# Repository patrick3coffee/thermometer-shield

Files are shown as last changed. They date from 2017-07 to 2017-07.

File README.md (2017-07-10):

# The Idea
I wanted a display of temperature and humidity and it exploded into this shield that functions as a thermostat, humidistat, and optostat (if that's even a word).
This project is my first attempt at creating a pcb. The design work is done in KiCAD. 

## Docs
See the PDF for the full shcematic and the SVGs for the inverted copper etching masks.

## Logical units of functionality
1. Display: this 4 digit, 7-segment display is driven by shift registers and transistors.
2. ULN2804 breakout: a transistor array for controlling 8 resistive or inductive loads.
    * Channels A through D plus G and H terminate to screw terminals. Channels G and H are connected in parallel to A and B respectively. This increases current capacity
    * Channels E through H terminat to pin headers.
    * To use G and H independently, four traces must be cut on the bottom of the board and the exposed inputs must connect to a desired arduino pin.
3. Button Array: Four buttons alter the output voltage in an array of voltage dividers
4. Photoresistor: Measures light.
5. RHT03: Measure temperatre and humidity.
6. I2C pin headers: allow for greater hackability.
7. All unused pins exposed.
    * D9 and D12
    * A2 and A3.
    * A4 and A5 in I2C header, but can be used for any purpose.

## The progression of scope creep  
There was more to this list that I think I forgot about, but these are the high points.
* Display temperature and humidity in garage. (done on a breadboard)  
* Do the same in the chicken coop.
* Make the hum/temp readings control things at specified thresholds.
* Make those thresholds settable on the front panel.
* Add a light sensor because the chicken coop needs the door shut at sunset and opened at sunrise.
* Expose all unused pins in useful ways for hackability.

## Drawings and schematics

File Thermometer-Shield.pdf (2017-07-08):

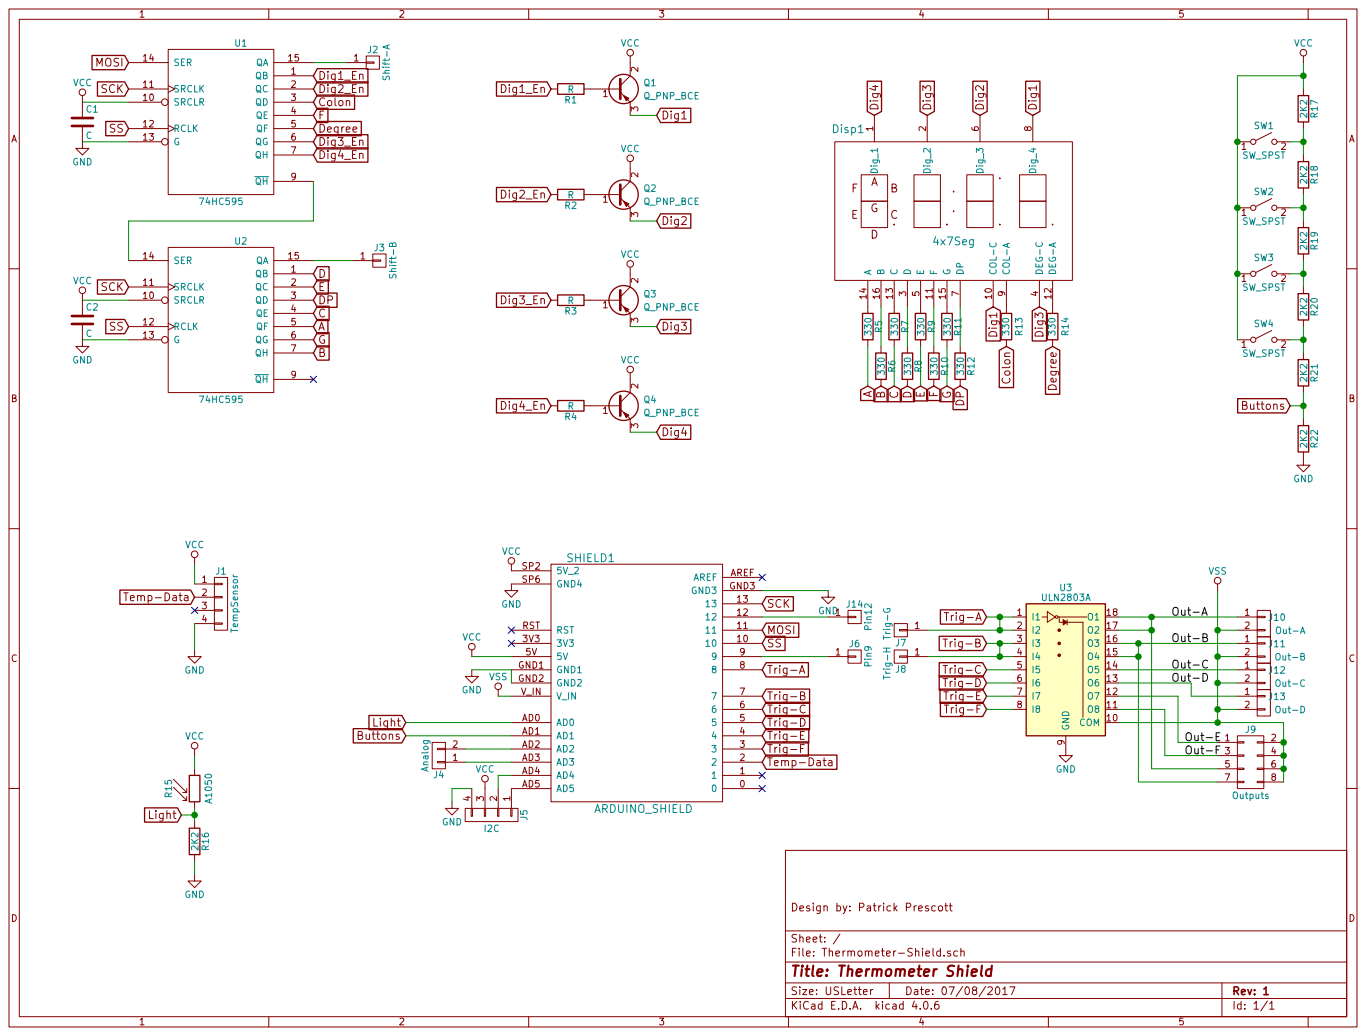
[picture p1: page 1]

Out-D | 2

Id: 1/1 Title: Thermometer Shield

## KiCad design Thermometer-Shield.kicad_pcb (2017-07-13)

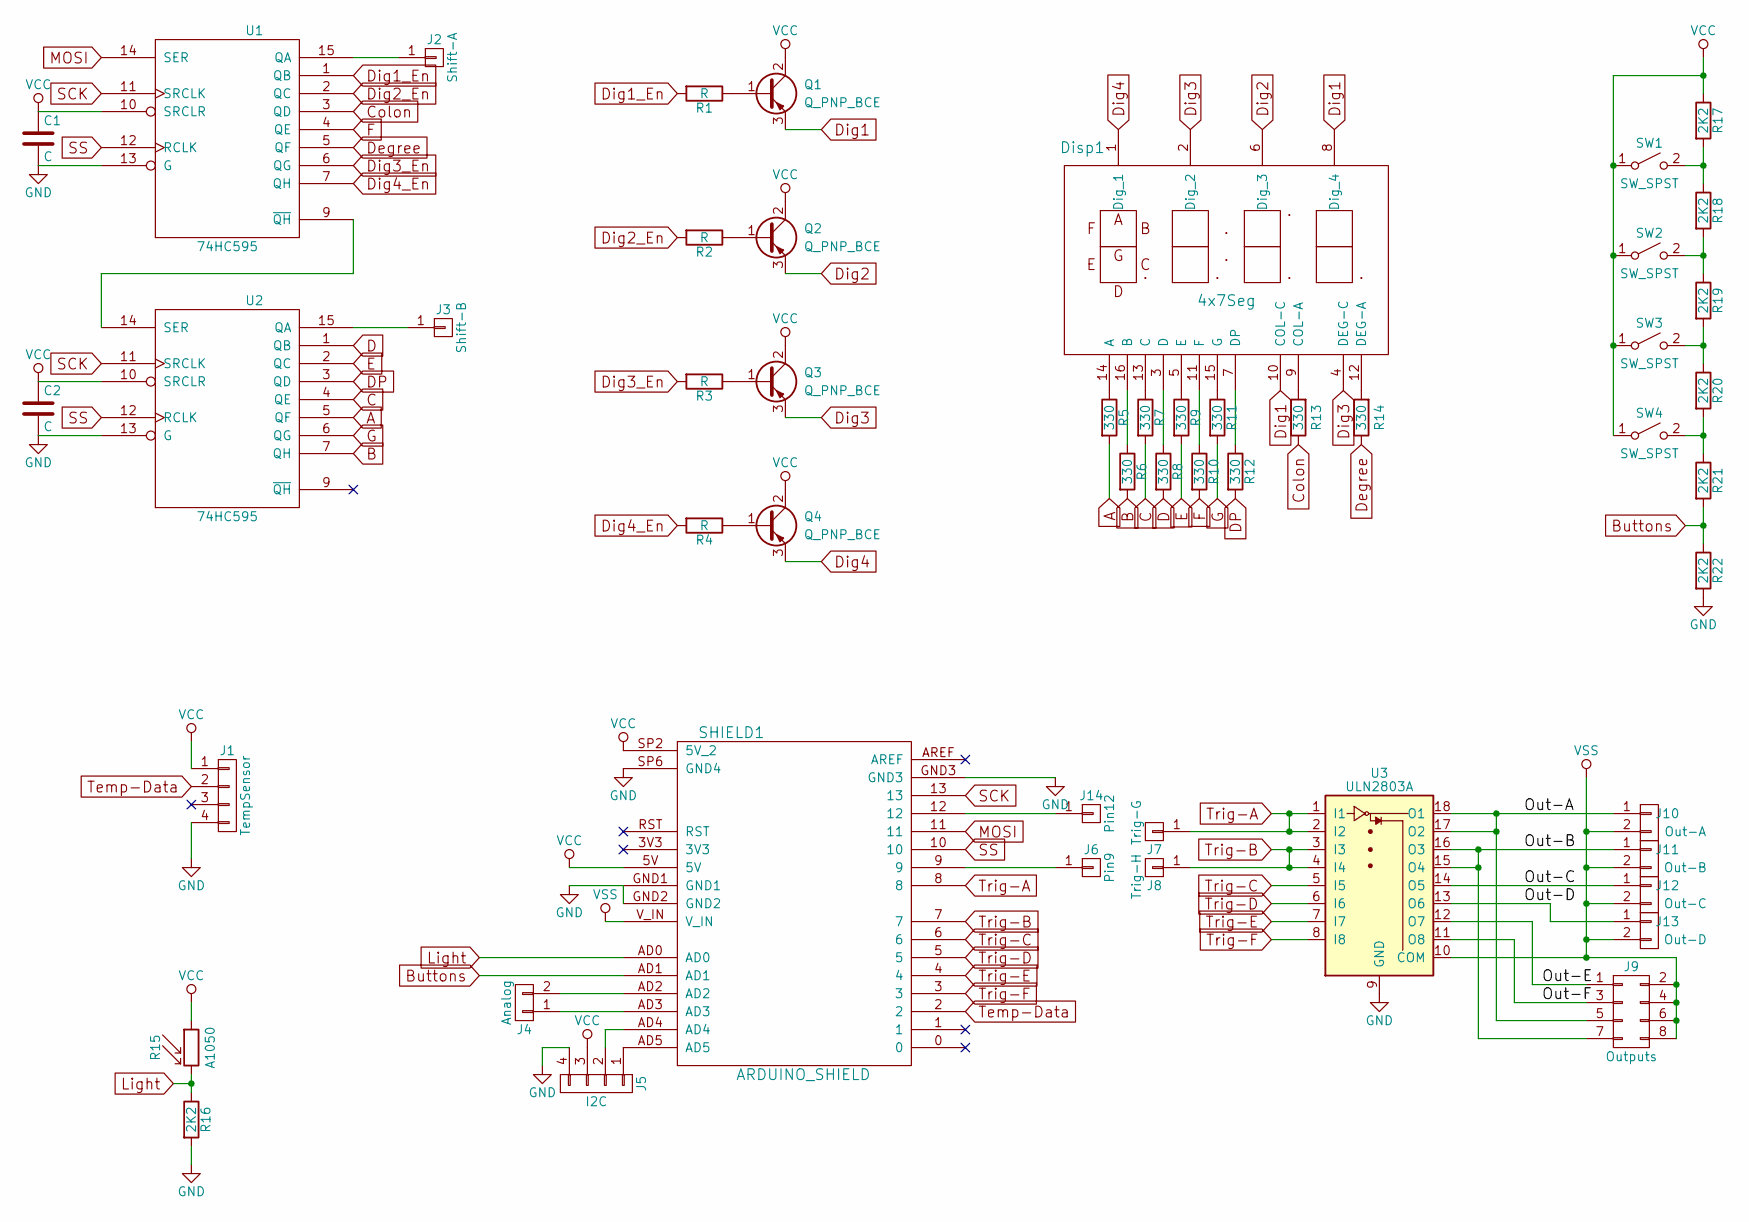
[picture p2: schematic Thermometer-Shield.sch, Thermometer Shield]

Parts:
C1, C2: C; C_Disc_D5.0mm_W2.5mm_P5.00mm
Disp1: 4x7Seg; ATA3492
J1: TempSensor; Pin_Header_Straight_1x04_Pitch2.54mm
J2: Shift-A; SolderWirePad_single_0-8mmDrill
J3: Shift-B; SolderWirePad_single_0-8mmDrill
J4: Analog; Pin_Header_Straight_1x02_Pitch2.54mm
J5: I2C; Pin_Header_Straight_1x04_Pitch2.54mm
J6: Pin9; Pin_Header_Straight_1x01_Pitch2.54mm
J7: Trig-G; SolderWirePad_single_0-8mmDrill
J8: Trig-H; SolderWirePad_single_0-8mmDrill
J9: Outputs; Pin_Header_Straight_2x04_Pitch2.54mm
J10: Out-A; AK300-2
J11: Out-B; AK300-2
J12: Out-C; AK300-2
J13: Out-D; AK300-2
J14: Pin12; Pin_Header_Straight_1x01_Pitch2.54mm
Q1, Q2, Q3, Q4: Q_PNP_BCE; TO-92_Inline_Narrow_Oval
R1, R2, R3, R4: R; R_0805_HandSoldering
R5, R6, R7, R8, R9, R10, R11, R12, R13, R14: 330; R_0603_HandSoldering
R15: A1050; Resistor_LDR_D6.4_RM3.4
R16, R17, R18, R19, R20, R21, R22: 2K2; R_0805_HandSoldering
SHIELD1: ARDUINO_SHIELD
SW1, SW2, SW3, SW4: SW_SPST; SW_PUSH_6mm
U1, U2: 74HC595; TSSOP-16_4.4x5mm_Pitch0.65mm
U3: ULN2803A; SOIC-18W_7.5x11.6mm_Pitch1.27mm

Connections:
/Out-A: J9.5, J10.1, U3.17 (O2), U3.18 (O1)
/Out-B: J9.7, J11.1, U3.15 (O4), U3.16 (O3)
/Out-C: J12.1, U3.14 (O5)
/Out-D: J13.1, U3.13 (O6)
/Out-E: J9.1, U3.12 (O7)
/Out-F: J9.3, U3.11 (O8)
A: R5.2, U2.5 (QF)
B: R6.2, U2.7 (QH)
Buttons: R21.2, R22.1, SHIELD1.AD1
C: R7.2, U2.4 (QE)
Colon: R13.1, U1.3 (QD)
D: R8.2, U2.1 (QB)
DP: R12.2, U2.3 (QD)
Degree: R14.1, U1.5 (QF)
Dig1: Disp1.8 (Dig_4), Disp1.10 (COL-C), Q1.3 (E)
Dig1_En: R1.2, U1.1 (QB)
Dig2: Disp1.6 (Dig_3), Q2.3 (E)
Dig2_En: R2.2, U1.2 (QC)
Dig3: Disp1.2 (Dig_2), Disp1.4 (DEG-C), Q3.3 (E)
Dig3_En: R3.2, U1.6 (QG)
Dig4: Disp1.1 (Dig_1), Q4.3 (E)
Dig4_En: R4.2, U1.7 (QH)
E: R9.2, U2.2 (QC)
F: R10.2, U1.4 (QE)
G: R11.2, U2.6 (QG)
GND: C1.2, C2.2, J1.4, J5.4, R16.2, R22.2, SHIELD1.GND1, SHIELD1.GND2, SHIELD1.GND3, SHIELD1.SP6 (GND4), U1.8 (GND), U1.13 (G), U2.8 (GND), U2.13 (G), U3.9 (GND)
Light: R15.2, R16.1, SHIELD1.AD0
MOSI: SHIELD1.11, U1.14 (SER)
unnamed: Disp1.3 (D), R8.1
unnamed: Disp1.5 (E), R9.1
unnamed: Disp1.7 (DP), R12.1
unnamed: Disp1.9 (COL-A), R13.2
unnamed: Disp1.11 (F), R10.1
unnamed: Disp1.12 (DEG-A), R14.2
unnamed: Disp1.13 (C), R7.1
unnamed: Disp1.14 (A), R5.1
unnamed: Disp1.15 (G), R11.1
unnamed: Disp1.16 (B), R6.1
unnamed: J2.1, U1.15 (QA)
unnamed: J3.1, U2.15 (QA)
unnamed: J4.1, SHIELD1.AD3
unnamed: J4.2, SHIELD1.AD2
unnamed: J5.1, SHIELD1.AD5
unnamed: J5.2, SHIELD1.AD4
unnamed: J6.1, SHIELD1.9
unnamed: J14.1, SHIELD1.12
unnamed: Q1.1 (B), R1.1
unnamed: Q2.1 (B), R2.1
unnamed: Q3.1 (B), R3.1
unnamed: Q4.1 (B), R4.1
unnamed: R17.2, R18.1, SW1.2 (B)
unnamed: R18.2, R19.1, SW2.2 (B)
unnamed: R19.2, R20.1, SW3.2 (B)
unnamed: R20.2, R21.1, SW4.2 (B)
unnamed: U1.9 (~QH), U2.14 (SER)
SCK: SHIELD1.13, U1.11 (SRCLK), U2.11 (SRCLK)
SS: SHIELD1.10, U1.12 (RCLK), U2.12 (RCLK)
Temp-Data: J1.2, SHIELD1.2
Trig-A: J7.1, SHIELD1.8, U3.1 (I1), U3.2 (I2)
Trig-B: J8.1, SHIELD1.7, U3.3 (I3), U3.4 (I4)
Trig-C: SHIELD1.6, U3.5 (I5)
Trig-D: SHIELD1.5, U3.6 (I6)
Trig-E: SHIELD1.4, U3.7 (I7)
Trig-F: SHIELD1.3, U3.8 (I8)
VCC: C1.1, C2.1, J1.1, J5.3, Q1.2 (C), Q2.2 (C), Q3.2 (C), Q4.2 (C), R15.1, R17.1, SHIELD1.5V, SHIELD1.SP2 (5V_2), SW1.1 (A), SW2.1 (A), SW3.1 (A), SW4.1 (A), U1.10 (SRCLR), U1.16 (VCC), U2.10 (SRCLR), U2.16 (VCC)
VSS: J9.2, J9.4, J9.6, J9.8, J10.2, J11.2, J12.2, J13.2, SHIELD1.V_IN, U3.10 (COM)

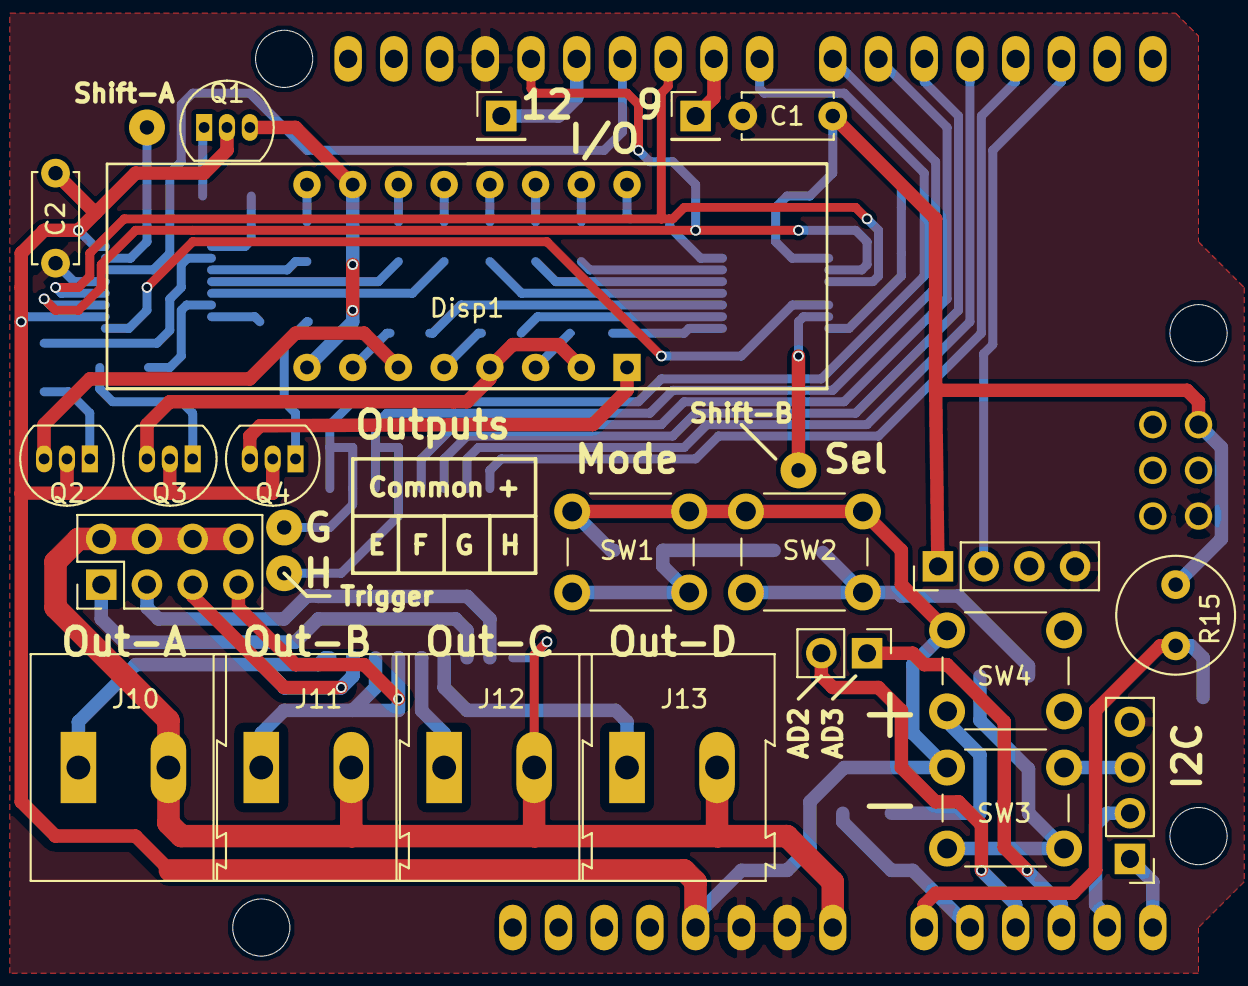
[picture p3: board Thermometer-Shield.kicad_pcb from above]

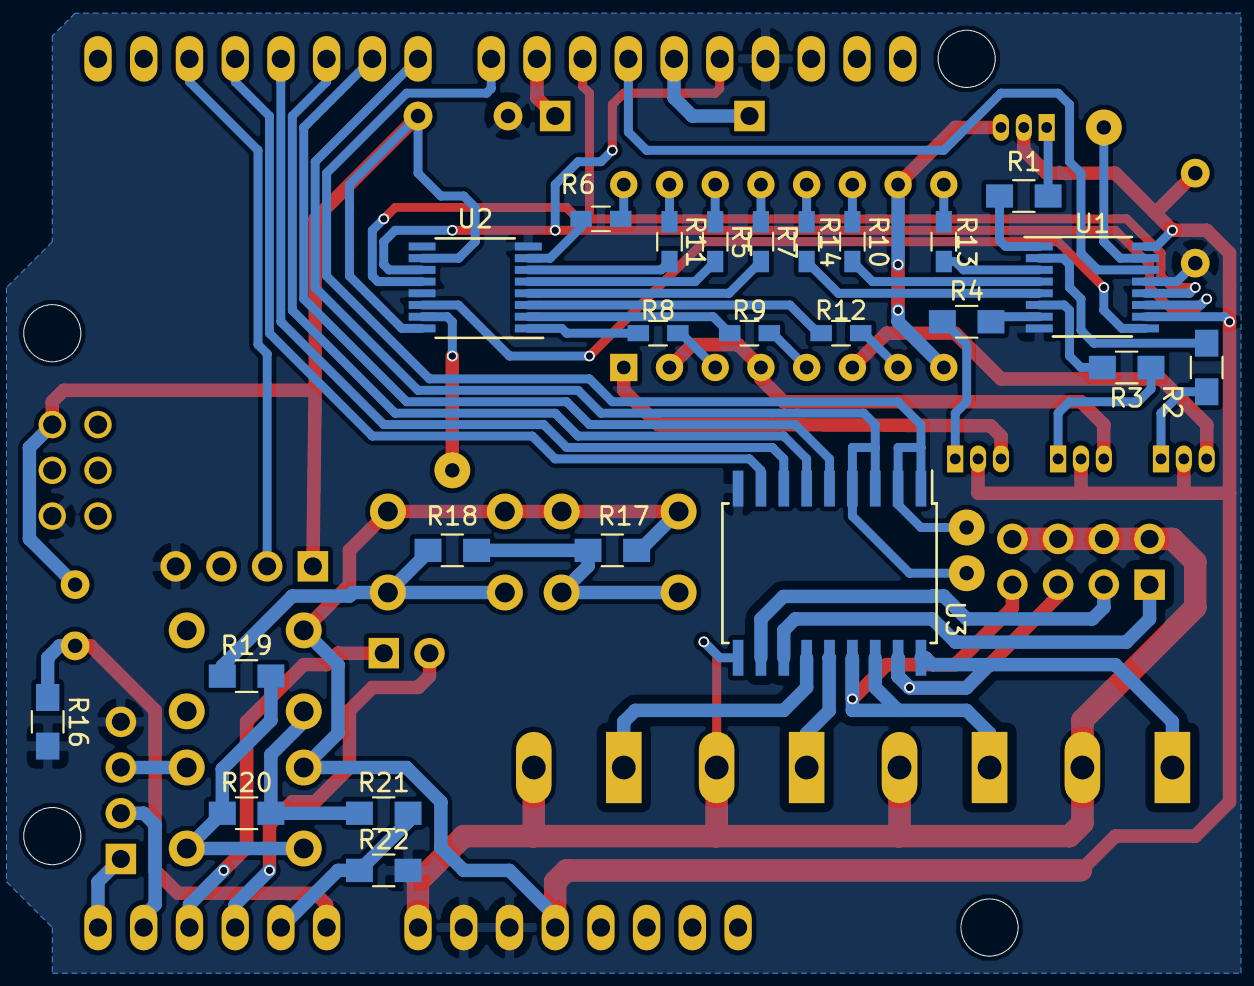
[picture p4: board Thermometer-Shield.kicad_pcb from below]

Board: 2 copper layers, 51 parts (24 on the bottom side), 66 nets.

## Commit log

2017-06-16 first commit. Schematic good, pcb needs love
    [Thermometer-Shield.kicad_pcb, Thermometer-Shield.sch]
2017-06-21 added documetation of parts, and some rework for more features
    [Thermometer-Shield.sch]
2017-06-21 added extension header with I2C layout
    [Thermometer-Shield.sch]
2017-06-25 started reworking for shift register
    [Thermometer-Shield.sch]
2017-06-26 schematic nearly done. PCB started
    [Thermometer-Shield.kicad_pcb, Thermometer-Shield.sch]
2017-07-05 completed schematic and pcb
    [Thermometer-Shield.kicad_pcb, Thermometer-Shield.sch]
2017-07-08 increased trace widths for etching
    [Thermometer-Shield.kicad_pcb]
2017-07-08 minor trace tweaks
    [Thermometer-Shield.kicad_pcb]
2017-07-08 Added schematic
    [Thermometer-Shield.sch]
2017-07-10 changed schematic page size to us letter, and plotted
    [Thermometer-Shield.kicad_pcb]
2017-07-13 arranged part labels for silk screen
    [Thermometer-Shield.kicad_pcb]
2017-07-13 silk screen fixes and additions
    [Thermometer-Shield.kicad_pcb]
